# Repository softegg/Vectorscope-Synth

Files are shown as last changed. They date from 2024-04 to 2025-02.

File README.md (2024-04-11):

# Music Synthesizer for the Hackaday Supercon 2024/ Europe 2024 Vectorscope Badge

This is an add on for the Hackaday Superconference 2023 / Hackaday Europe(Berlin) 2024 Vectorscope badge that adds a small virtual analog synthesizer based on the [Stylish Trucker Belt Synthesizer](https://github.com/softegg/Stylish-Trucker-Belt-Synthesizer).

It should work with all of the source code from that, so for now get it there.
This has not yet been tested, so if you want to build one, be aware that it might be broken. In particular, I'm worried that the two batteries in the badge might not have the oomph to drive the vectorscope with the RPI 2040 and screen as well as the synth's Bluepill STM32, LED ring, and amplifier.

This might need additional battery or USB power support.

The design is very much in flux as we have very limited time before the show, and the modules used in the end product are going to be limited by what we can get delivered quickly in Berlin, as two week+ lead times for AliExpress parts are just not doable!
This is intended for a workshop, but we've been reluctant to commit before we are sure that it will work and that we can get the parts.

So, you might be able to do a $20 workshop and get one, or you might have to go find parts and build your own. It might work, or it might be crap.

There is so much we don't know.

I hope you can enjoy it, at least!!

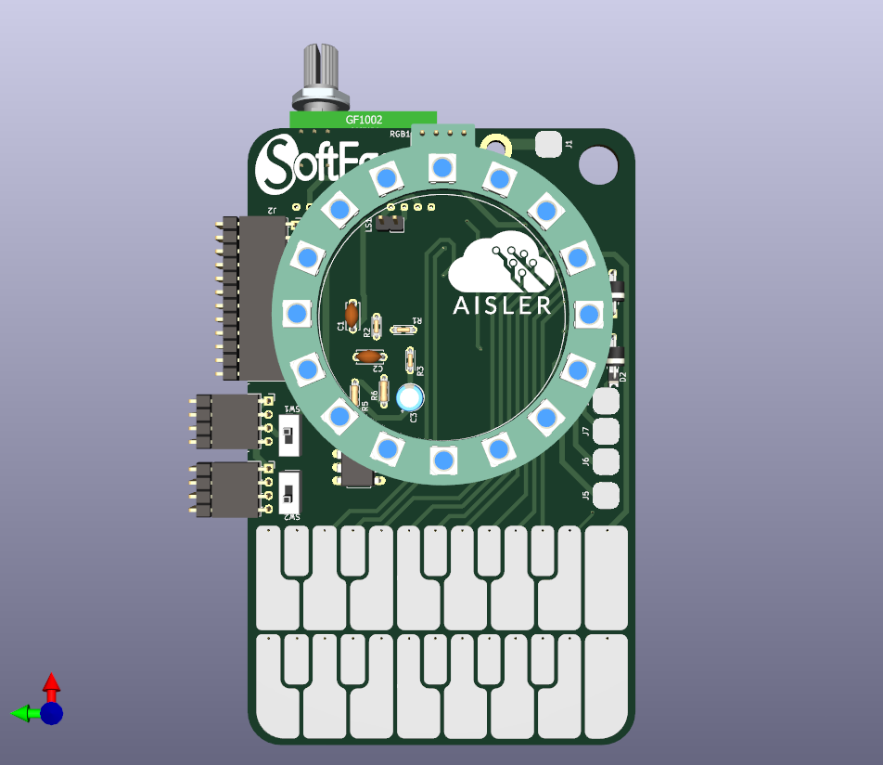
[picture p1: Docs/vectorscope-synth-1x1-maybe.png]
Vectorscope Synth Front


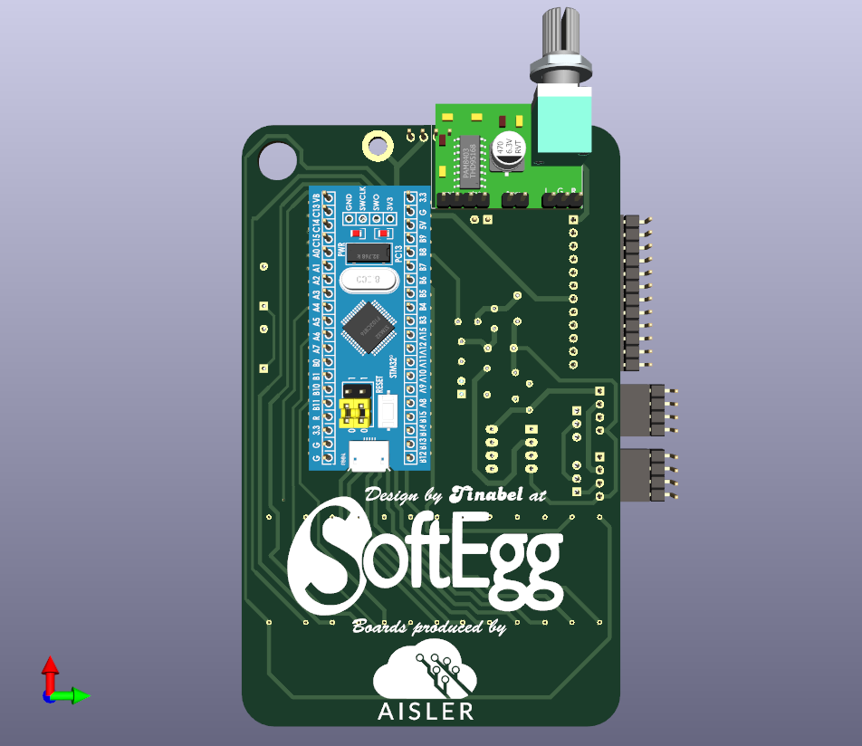
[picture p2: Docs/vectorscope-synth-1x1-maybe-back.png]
Vectorscope Synth Back


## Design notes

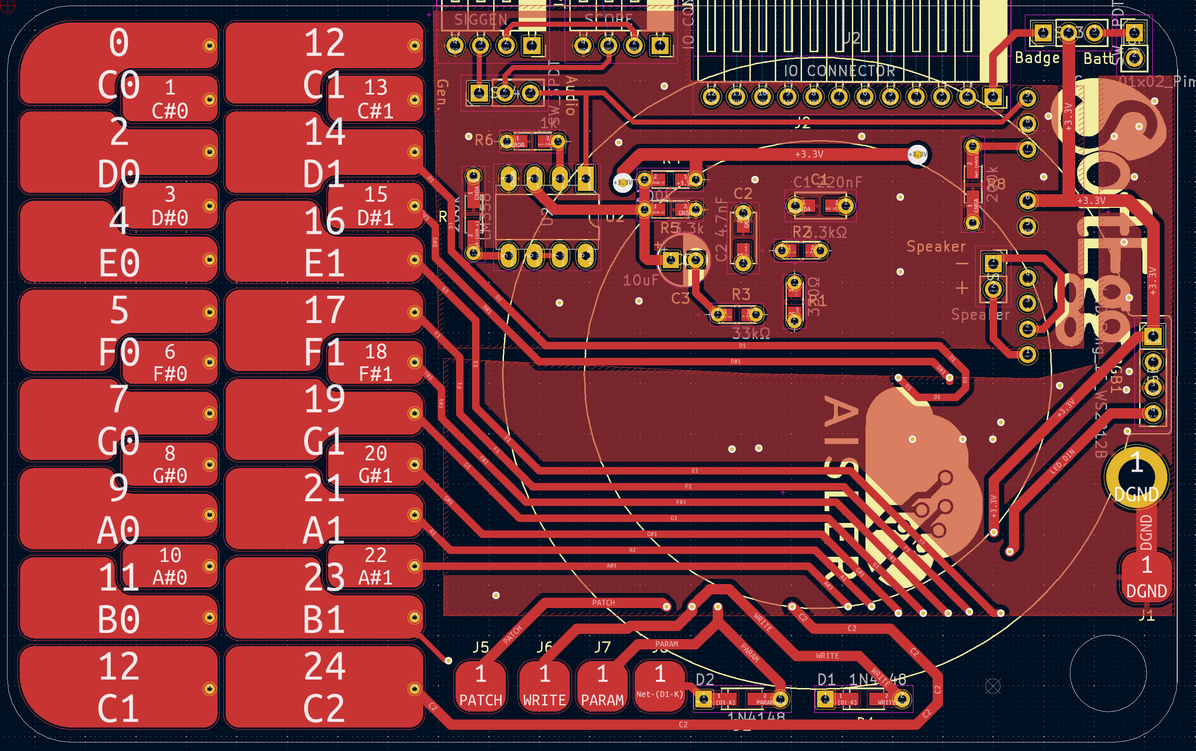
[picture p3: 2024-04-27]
Docs/Vectorscope Synth PCB front CAD.PNG

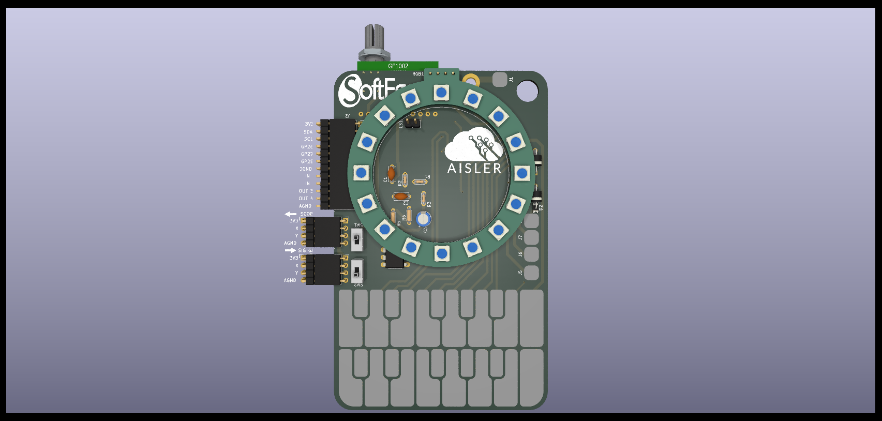
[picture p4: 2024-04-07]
Docs/vectorscope-synth-16x9-maybe-ray.png

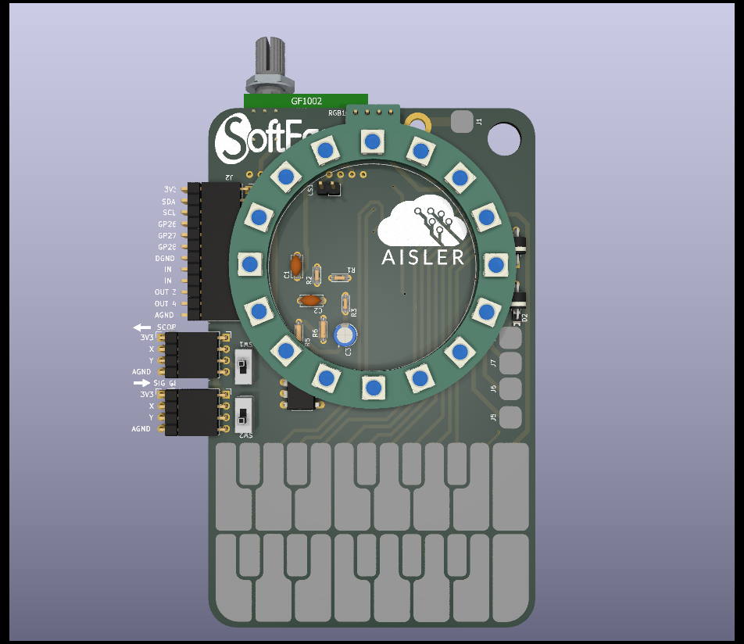
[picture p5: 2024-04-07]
Docs/vectorscope-synth-1x1-maybe-ray.png

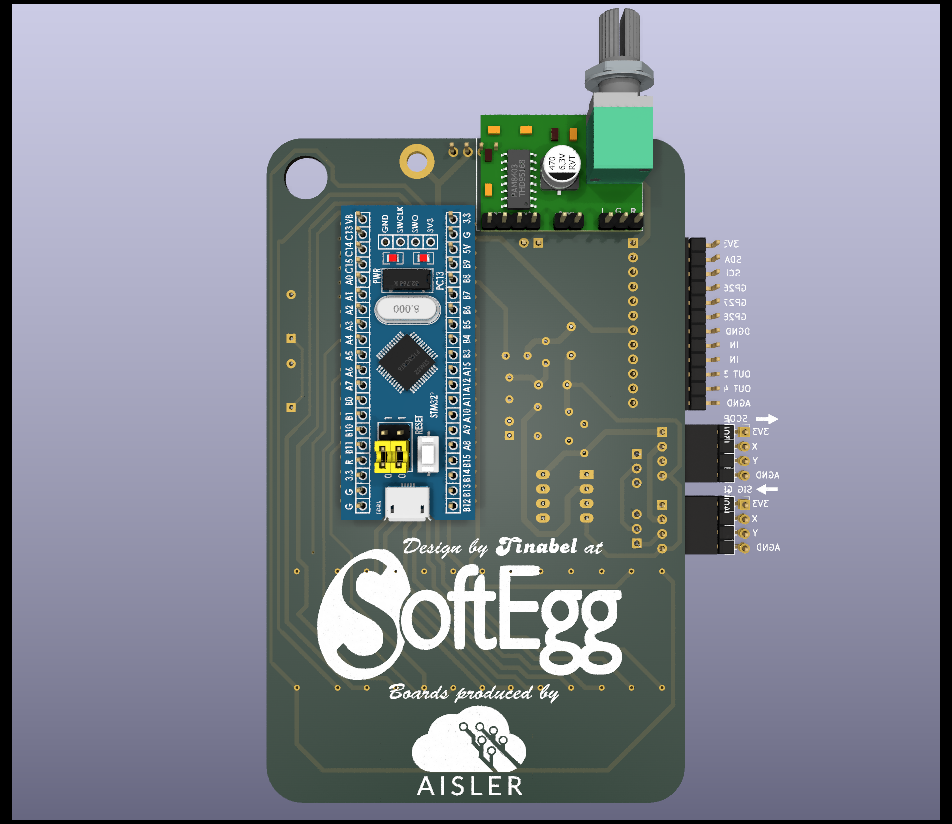
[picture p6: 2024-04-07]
Docs/vectorscope-synth-1x1-maybe-back-ray.png

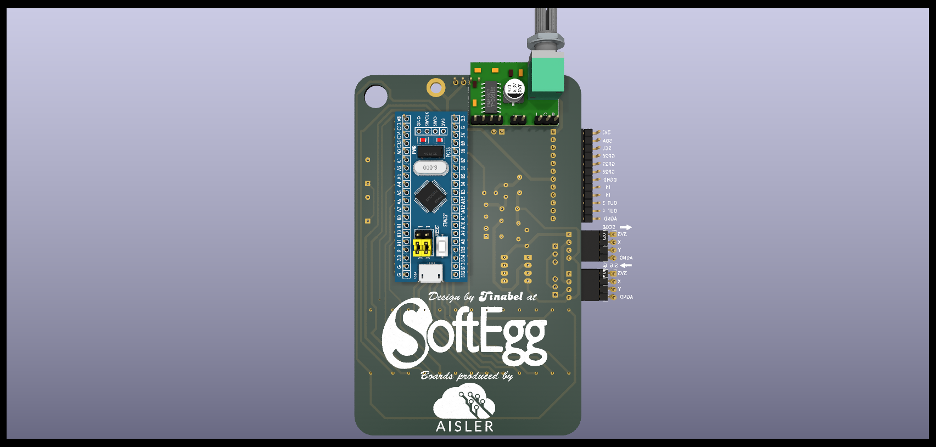
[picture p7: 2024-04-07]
Docs/vectorscope-synth-16x9-maybe-back-ray.png

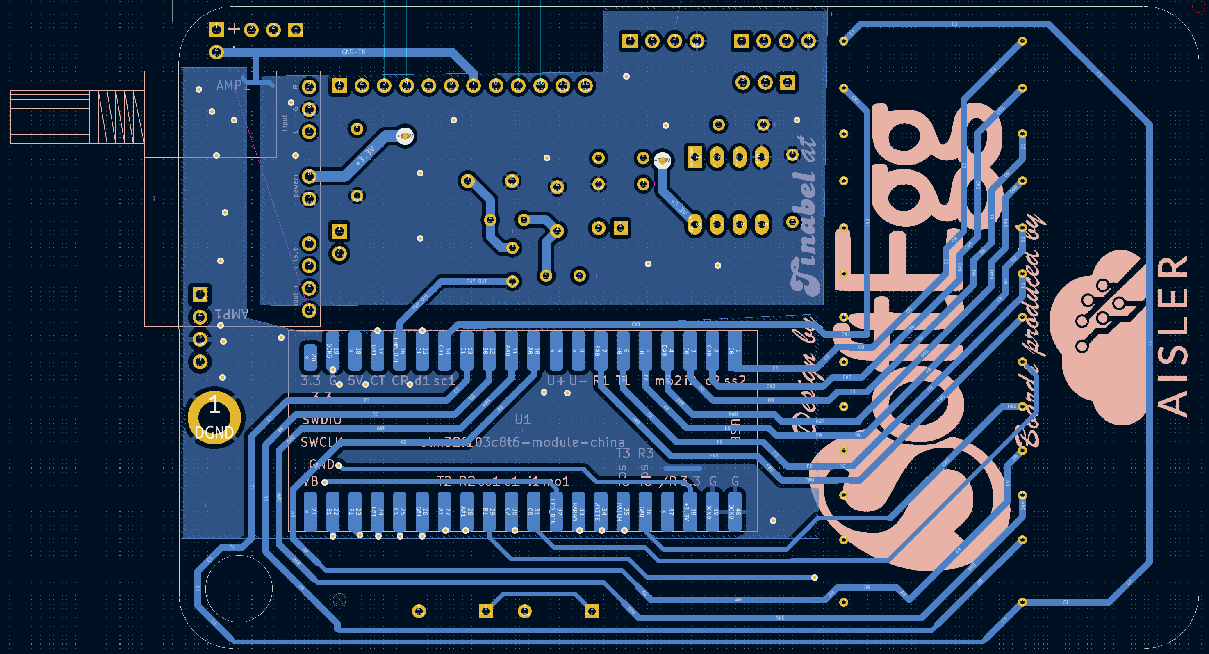
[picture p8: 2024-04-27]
Docs/Vectorscope Synth PCB back CAD.PNG

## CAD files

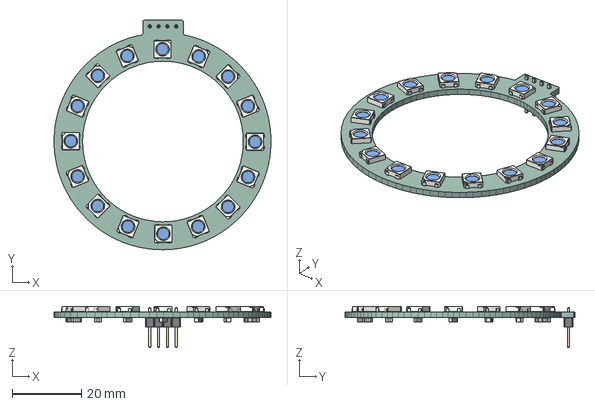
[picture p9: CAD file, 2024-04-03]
WS2812B-16-LED-RING.step
62.6 x 66.2 x 11.9 mm
WS2812B-16-LED-RING PCB

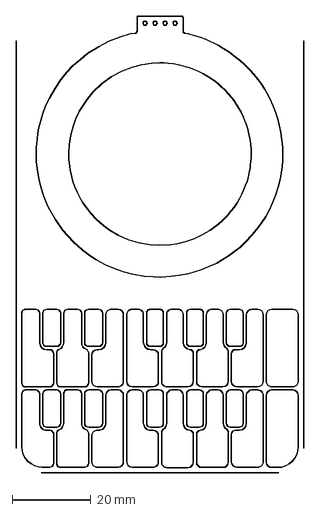
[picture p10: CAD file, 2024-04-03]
StylusKeyboardLayout.dxf
73.0 x 116.0 mm

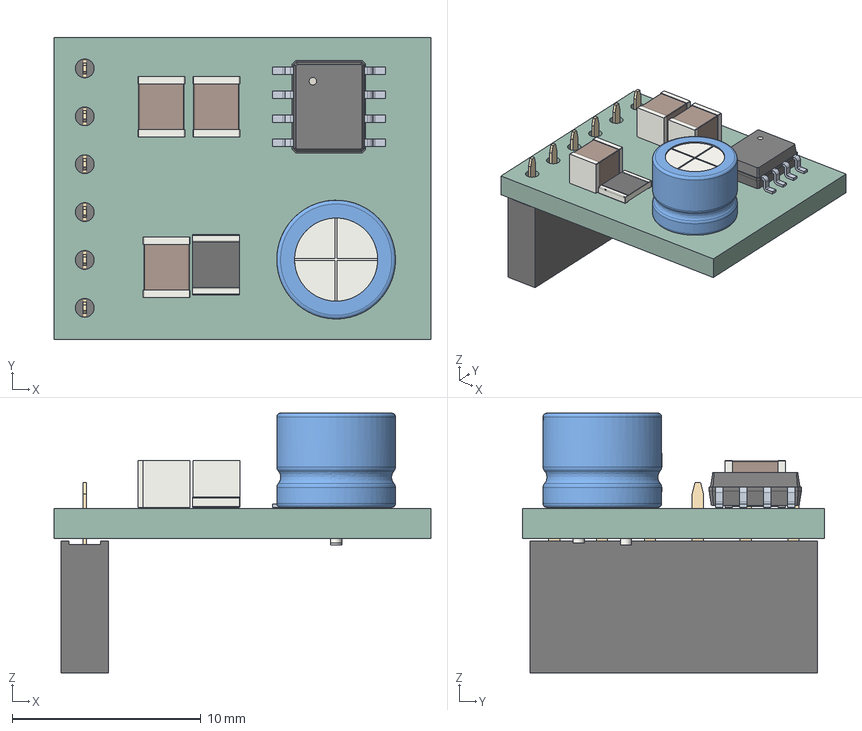
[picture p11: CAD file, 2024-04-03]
XH-M125-amp-board.step
20.0 x 16.0 x 13.8 mm
XH-M125-amp-board PCB

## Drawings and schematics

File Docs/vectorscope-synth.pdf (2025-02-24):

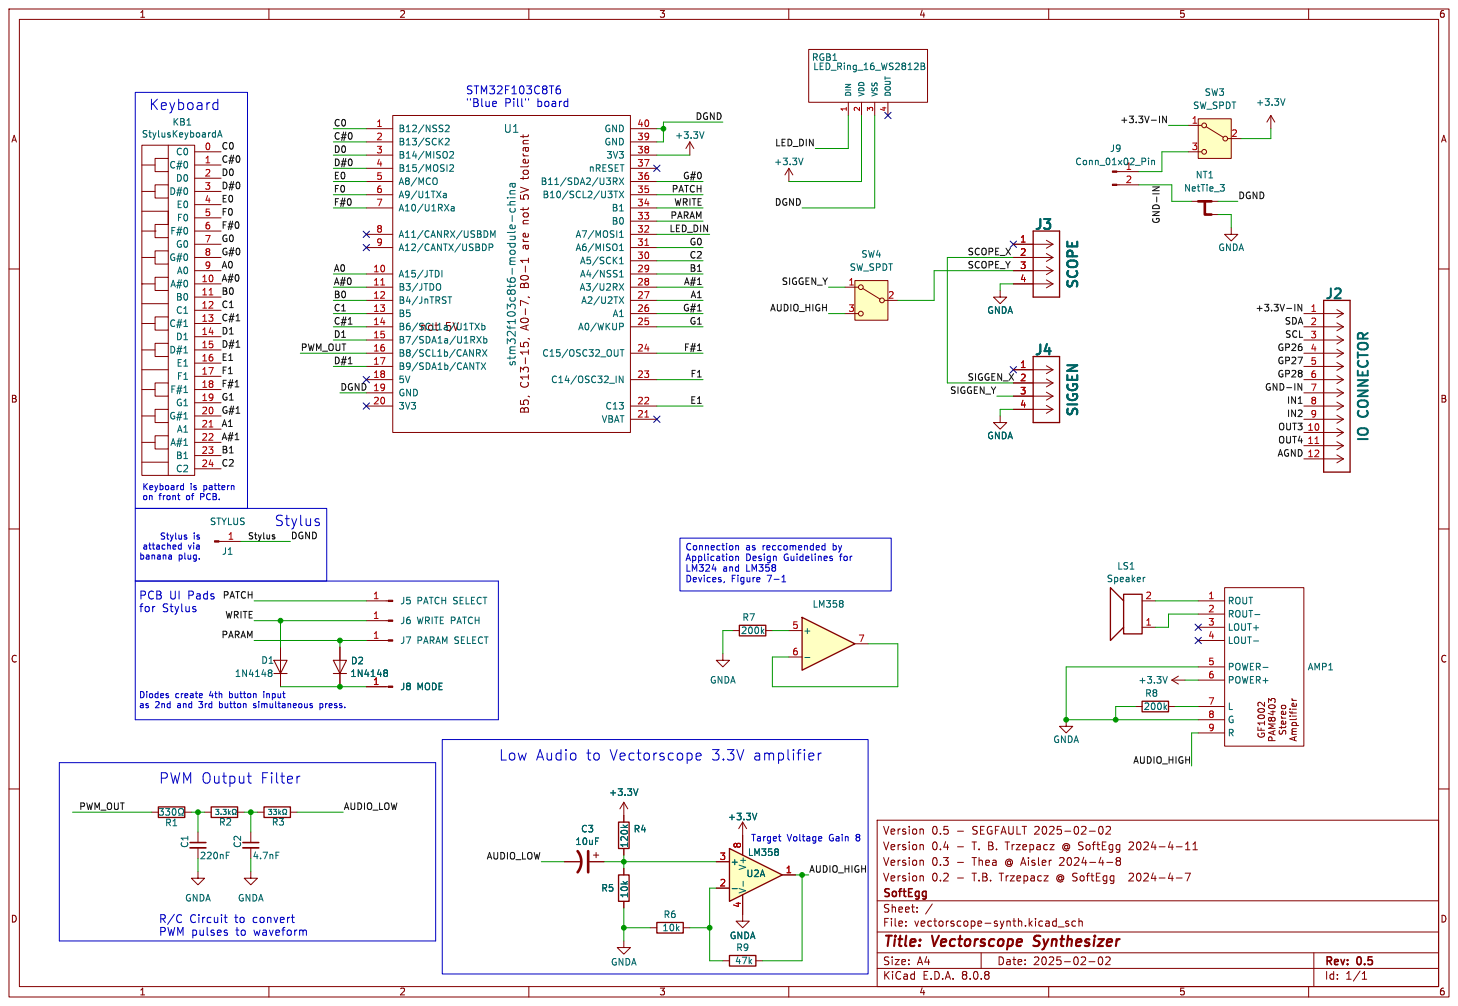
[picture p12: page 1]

"Blue Pill" board PWM Output Filter

4.7nF GNDA R1
Target Voltage Gain 8 R/C Circuit to convert PWM pulses to waveform

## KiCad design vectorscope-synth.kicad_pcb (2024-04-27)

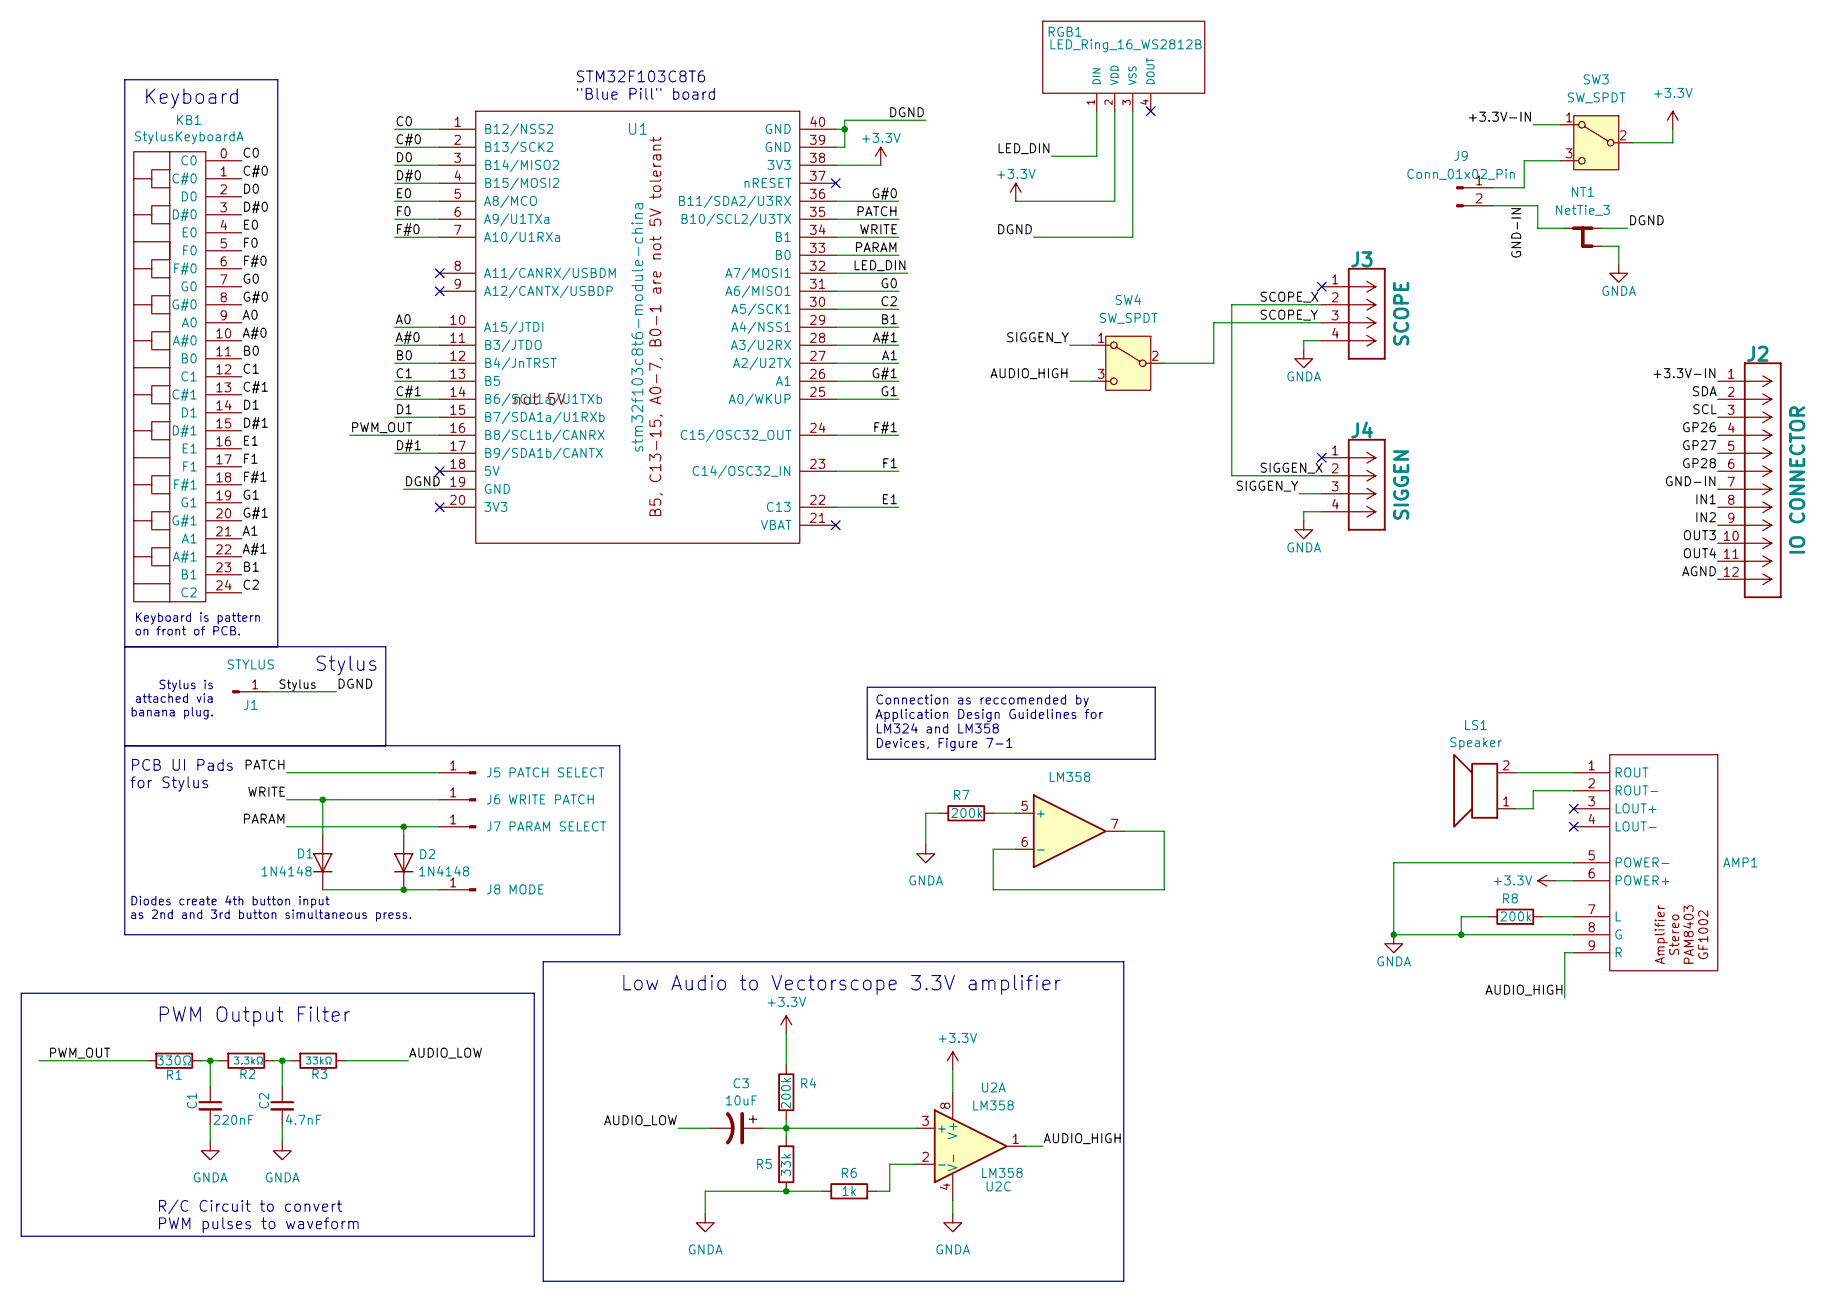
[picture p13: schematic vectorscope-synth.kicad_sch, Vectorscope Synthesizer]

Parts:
AMP1: GF1002-PAM8403_Amplifier_Module
C1: 220nF; C_Disc_D5.0mm_W2.5mm_P5.00mm+SMD
C2: 4.7nF; C_Disc_D5.0mm_W2.5mm_P5.00mm+SMD
C3: 10uF; CP_Radial_D5.0mm_P2.50mm
D1, D2: 1N4148; D_DO-35_SOD27_P7.62mm_Horizontal+SMD
J1: STYLUS; SmallRoundTouchPad
J2: IO CONNECTOR; PinSocket_1x12_P2.54mm_Horizontal
J3: SCOPE; PinSocket_1x04_P2.54mm_Horizontal
J4: SIGGEN; PinSocket_1x04_P2.54mm_Horizontal
J5: PATCH SELECT; SmallRoundTouchPad
J6: WRITE PATCH; SmallRoundTouchPad
J7: PARAM SELECT; SmallRoundTouchPad
J8: MODE; SmallRoundTouchPad
J9: Conn_01x02_Pin; PinHeader_1x02_P2.54mm_Vertical
KB1: StylusKeyboardA; StylusKeyboard
LS1: Speaker; PinSocket_1x02_P2.54mm_Vertical
NT1: NetTie_3; NetTie-3_SMD_Pad0.5mm
R1: 330Ω; R_Axial_DIN0204_L3.6mm_D1.6mm_P3.81mm_Horizontal+SMD804
R2: 3.3kΩ; R_Axial_DIN0204_L3.6mm_D1.6mm_P3.81mm_Horizontal+SMD804
R3: 33kΩ; R_Axial_DIN0204_L3.6mm_D1.6mm_P3.81mm_Horizontal+SMD804
R4: 200k; R_Axial_DIN0204_L3.6mm_D1.6mm_P5mm_Horizontal+SMD804
R5: 33k; R_Axial_DIN0204_L3.6mm_D1.6mm_P5mm_Horizontal+SMD804
R6: 1k; R_Axial_DIN0204_L3.6mm_D1.6mm_P5mm_Horizontal+SMD804
R7, R8: 200k; R_Axial_DIN0204_L3.6mm_D1.6mm_P7.62mm_Horizontal+SMD804
RGB1: LED_Ring_16_WS2812B; LED RING 16 WS2812B
SW3, SW4: SW_SPDT; PinHeader_1x03_P2.54mm_Vertical
U1: stm32f103c8t6-module-china; stm32f103c8t6-module-china-smd
U2: LM358; DIP-8_W7.62mm_LongPads

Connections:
+3.3V: AMP1.6 (POWER+), R4.1, RGB1.2 (VDD), SW3.2 (B), U1.38 (3V3), U2.8 (V+)
/+3.3V-IN: J2.1, SW3.1 (A)
/A0: KB1.9 (A0), U1.10 (A15/JTDI)
/A1: KB1.21 (A1), U1.27 (A2/U2TX)
/A#0: KB1.10 (A#0), U1.11 (B3/JTDO)
/A#1: KB1.22 (A#1), U1.28 (A3/U2RX)
/AGND: J2.12
/AUDIO_HIGH: AMP1.9 (R), SW4.3 (C), U2.1
/AUDIO_LOW: C3.2, R3.1
/B0: KB1.11 (B0), U1.12 (B4/JnTRST)
/B1: KB1.23 (B1), U1.29 (A4/NSS1)
/C0: KB1.0 (C0), U1.1 (B12/NSS2)
/C1: KB1.12 (C1), U1.13 (B5)
/C2: KB1.24 (C2), U1.30 (A5/SCK1)
/C#0: KB1.1 (C#0), U1.2 (B13/SCK2)
/C#1: KB1.13 (C#1), U1.14 (B6/SCL1a/U1TXb)
/D0: KB1.2 (D0), U1.3 (B14/MISO2)
/D1: KB1.14 (D1), U1.15 (B7/SDA1a/U1RXb)
/D#0: KB1.3 (D#0), U1.4 (B15/MOSI2)
/D#1: KB1.15 (D#1), U1.17 (B9/SDA1b/CANTX)
/DGND: J1.1, NT1.1, RGB1.3 (VSS), U1.19 (GND), U1.39 (GND), U1.40 (GND)
/E0: KB1.4 (E0), U1.5 (A8/MCO)
/E1: KB1.16 (E1), U1.22 (C13)
/F0: KB1.5 (F0), U1.6 (A9/U1TXa)
/F1: KB1.17 (F1), U1.23 (C14/OSC32_IN)
/F#0: KB1.6 (F#0), U1.7 (A10/U1RXa)
/F#1: KB1.18 (F#1), U1.24 (C15/OSC32_OUT)
/G0: KB1.7 (G0), U1.31 (A6/MISO1)
/G1: KB1.19 (G1), U1.25 (A0/WKUP)
/G#0: KB1.8 (G#0), U1.36 (B11/SDA2/U3RX)
/G#1: KB1.20 (G#1), U1.26 (A1)
/GND-IN: J2.7, J9.2, NT1.2
/GP26: J2.4; also elsewhere on the board
/GP27: J2.5; also elsewhere on the board
/GP28: J2.6; also elsewhere on the board
/IN1: J2.8; also elsewhere on the board
/IN2: J2.9; also elsewhere on the board
/LED_DIN: RGB1.1 (DIN), U1.32 (A7/MOSI1)
/OUT3: J2.10; also elsewhere on the board
/OUT4: J2.11; also elsewhere on the board
/PARAM: D2.2 (A), J7.1, U1.33 (B0)
/PATCH: J5.1, U1.35 (B10/SCL2/U3TX)
/PWM_OUT: R1.2, U1.16 (B8/SCL1b/CANRX)
/SCL: J2.3; also elsewhere on the board
/SCOPE_X: J3.2, J4.2
/SCOPE_Y: J3.3, SW4.2 (B)
/SDA: J2.2; also elsewhere on the board
/SIGGEN_Y: J4.3, SW4.1 (A)
/WRITE: D1.2 (A), J6.1, U1.34 (B1)
GNDA: AMP1.5 (POWER-), AMP1.8 (G), C1.2, C2.2, J3.4, J4.4, NT1.3, R5.2, R6.1, R7.1, R8.1, U2.4 (V-); also elsewhere on the board
unnamed: AMP1.7 (L), R8.2
unnamed: AMP1.1 (ROUT), LS1.2
unnamed: AMP1.2 (ROUT-), LS1.1
unnamed: C1.1, R1.1, R2.2
unnamed: C2.1, R2.1, R3.2
unnamed: D1.1 (K), D2.1 (K), J8.1
unnamed: J9.1, SW3.3 (C)
unnamed: C3.1, R4.2, R5.1, U2.3 (+)
unnamed: R6.2, U2.2 (-)
unnamed: R7.2, U2.5 (+)
unnamed: U2.6 (-), U2.7

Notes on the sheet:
Connection as reccomended by Application Design Guidelines for LM324 and LM358 Devices, Figure 7-1
Stylus
PWM Output Filter
STM32F103C8T6 "Blue Pill" board
R/C Circuit to convert PWM pulses to waveform
Keyboard is pattern on front of PCB.
PCB UI Pads for Stylus
Keyboard
Low Audio to Vectorscope 3.3V amplifier
Stylus is attached via banana plug.
Diodes create 4th button input as 2nd and 3rd button simultaneous press.

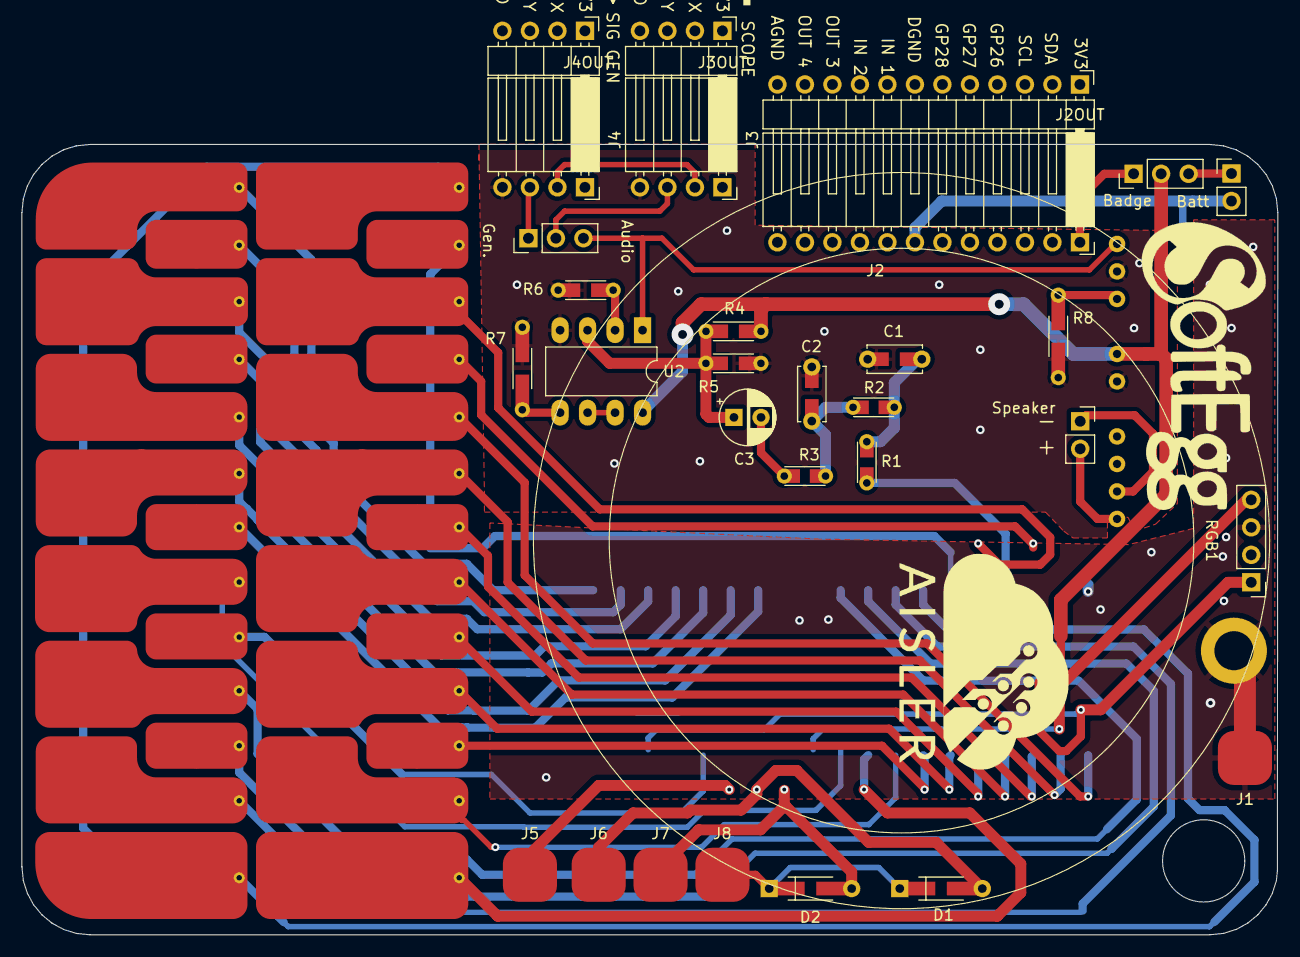
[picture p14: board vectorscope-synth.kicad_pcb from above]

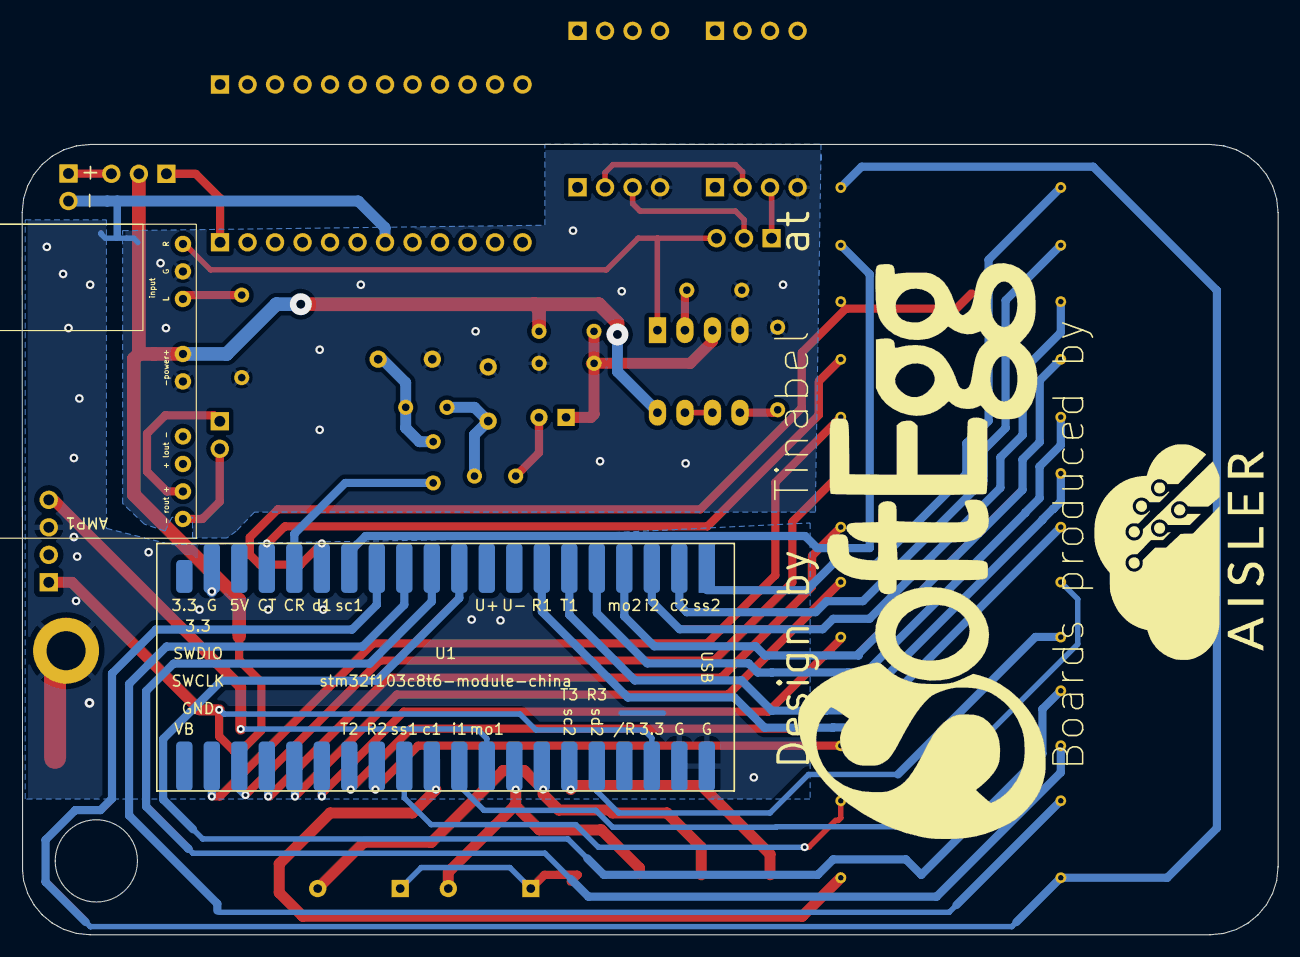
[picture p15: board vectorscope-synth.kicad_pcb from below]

Board: 2 copper layers, 116.0 x 73.0 mm, 34 parts (3 on the bottom side), 60 nets.

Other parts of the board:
J2OUT: IO CONNECTOR; PinHeader_1x12_P2.54mm_Horizontal
J3OUT: SCOPE; PinHeader_1x04_P2.54mm_Horizontal
J4OUT: SIGGEN; PinHeader_1x04_P2.54mm_Horizontal

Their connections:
/GP26: J2OUT.4; also elsewhere on the board
/GP27: J2OUT.5; also elsewhere on the board
/GP28: J2OUT.6; also elsewhere on the board
/IN1: J2OUT.8; also elsewhere on the board
/IN2: J2OUT.9; also elsewhere on the board
/OUT3: J2OUT.10; also elsewhere on the board
/OUT4: J2OUT.11; also elsewhere on the board
/SCL: J2OUT.3; also elsewhere on the board
/SDA: J2OUT.2; also elsewhere on the board
GNDA: J3OUT.4, J4OUT.4; also elsewhere on the board

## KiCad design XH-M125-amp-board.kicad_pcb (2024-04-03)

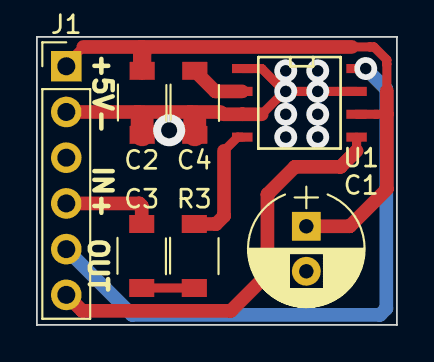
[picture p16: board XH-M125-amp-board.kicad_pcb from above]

Board: 2 copper layers, 20.0 x 16.0 mm, 7 parts (0 on the bottom side), 8 nets.

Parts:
C1: 470uF; CP_Radial_D6.3mm_P2.50mm
C2, C4: 1uF; C_1509
C3: 0.39uF; C_1509
J1: Conn_01x06; Pin_Header_Straight_1x06_Pitch2.54mm
R3: R; C_1509
U1: XPT8871; SOIC-8-N

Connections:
/GND: C1.2, C2.2, C4.2, J1.2, J1.3, U1.1, U1.3, U1.7
/VCC: C1.1, C2.1, J1.1, U1.6
/VIN: C3.2, J1.4
/VO1: J1.6, U1.5
/VO2: J1.5, U1.8
unnamed: C3.1, R3.2
unnamed: C4.1, U1.2
unnamed: R3.1, U1.4

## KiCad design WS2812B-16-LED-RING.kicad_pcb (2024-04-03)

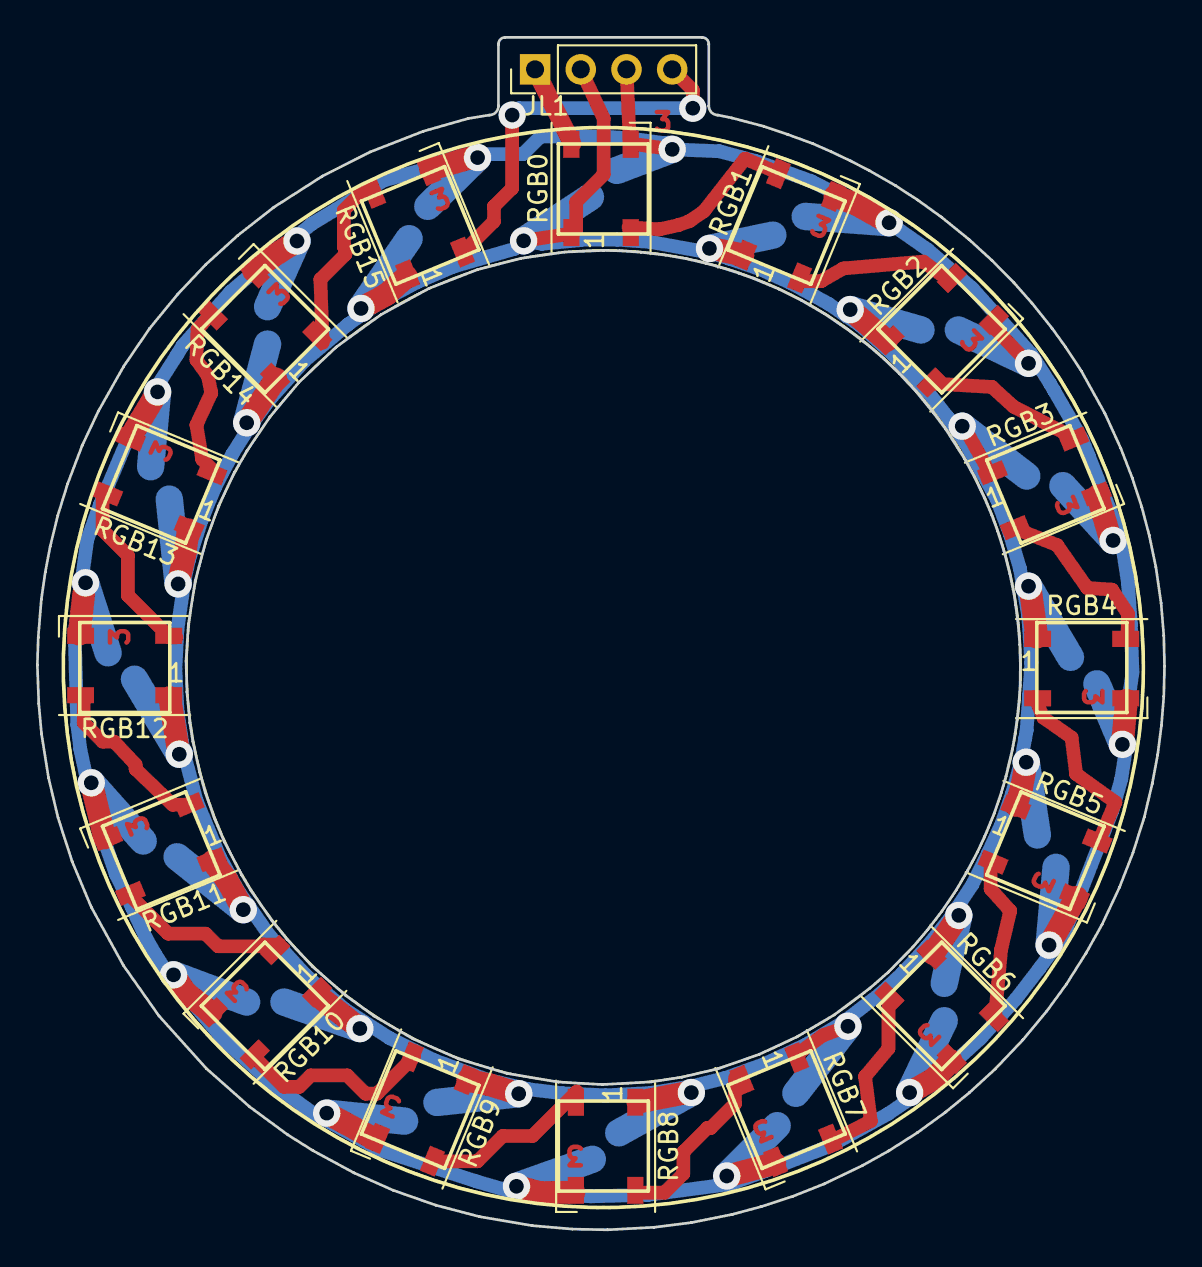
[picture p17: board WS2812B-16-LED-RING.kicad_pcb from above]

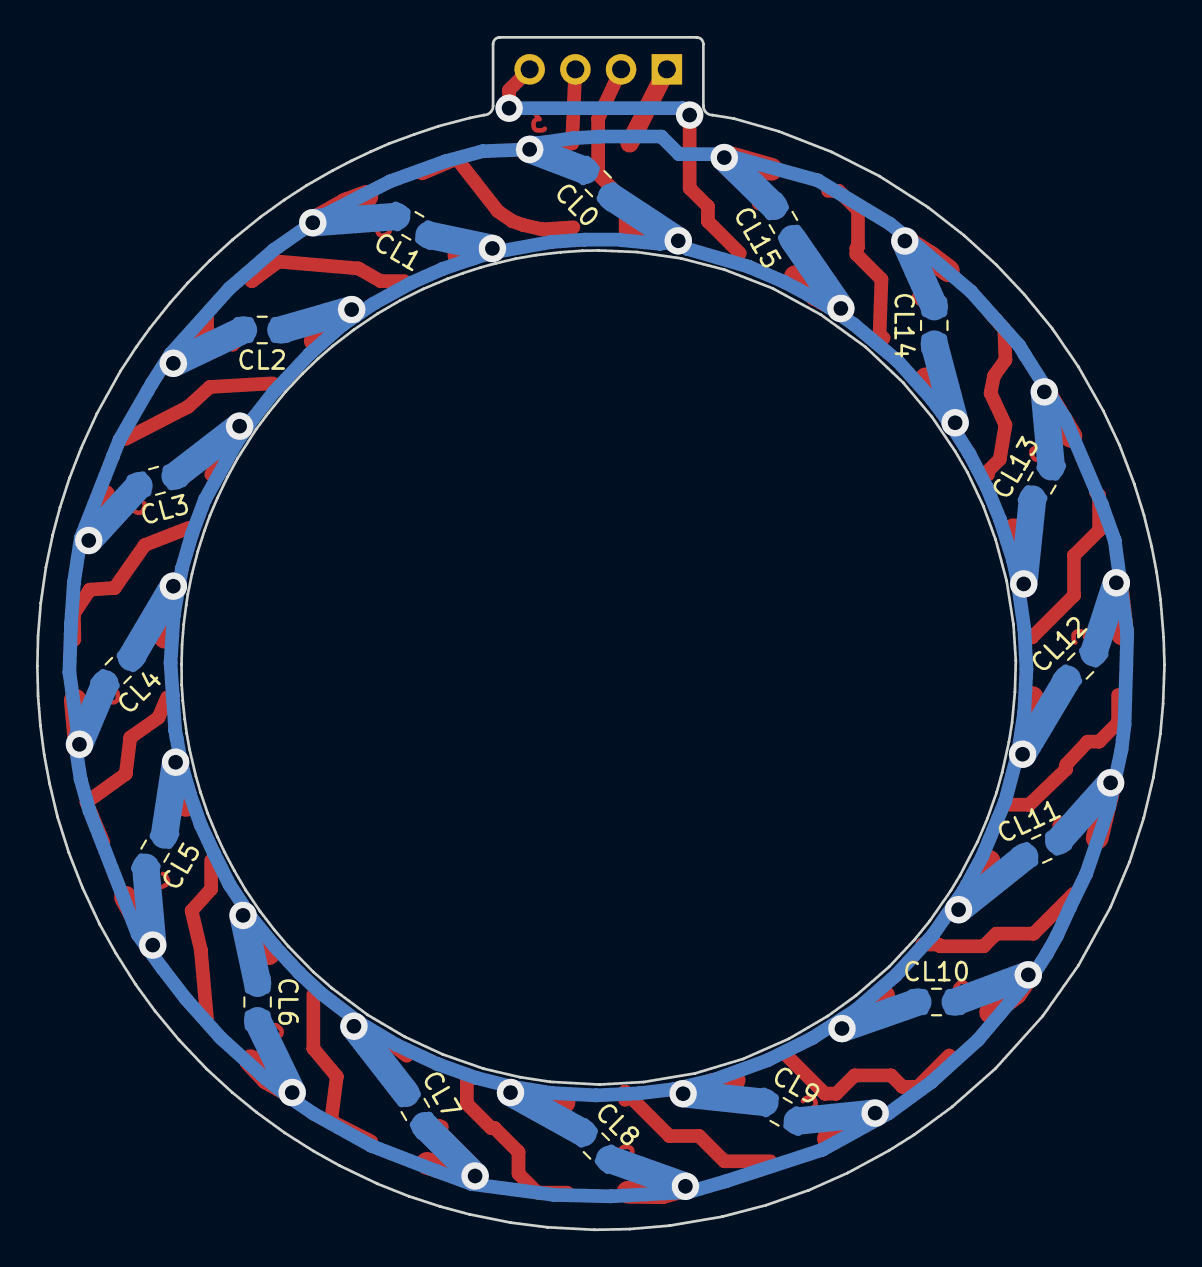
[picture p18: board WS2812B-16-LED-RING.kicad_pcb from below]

Board: 2 copper layers, 62.6 x 66.2 mm, 33 parts (16 on the bottom side), 19 nets.

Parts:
CL0, CL1, CL2, CL3, CL4, CL5, CL6, CL7, CL8, CL9, CL10, CL11, CL12, CL13, CL14, CL15: 104; C_0805_2012Metric_Pad1.18x1.45mm_HandSolder
JL1: Pin_Header_Straight_1x04_Pitch2.54mm
RGB0, RGB1, RGB2, RGB3, RGB4, RGB5, RGB6, RGB7, RGB8, RGB9, RGB10, RGB11, RGB12, RGB13, RGB14, RGB15: WS2812B; LED_WS2812B_PLCC4_5.0x5.0mm_P3.2mm

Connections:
/DIN: JL1.1, RGB0.4 (DIN)
/DOUT: JL1.4, RGB15.2 (DOUT)
/VIN: CL0.1, CL1.1, CL2.1, CL3.1, CL4.1, CL5.1, CL6.1, CL7.1, CL8.1, CL9.1, CL10.1, CL11.1, CL12.1, CL13.1, CL14.1, CL15.1, JL1.2, RGB0.1 (VDD), RGB1.1 (VDD), RGB2.1 (VDD), RGB3.1 (VDD), RGB4.1 (VDD), RGB5.1 (VDD), RGB6.1 (VDD), RGB7.1 (VDD), RGB8.1 (VDD), RGB9.1 (VDD), RGB10.1 (VDD), RGB11.1 (VDD), RGB12.1 (VDD), RGB13.1 (VDD), RGB14.1 (VDD), RGB15.1 (VDD)
GND: CL0.2, CL1.2, CL2.2, CL3.2, CL4.2, CL5.2, CL6.2, CL7.2, CL8.2, CL9.2, CL10.2, CL11.2, CL12.2, CL13.2, CL14.2, CL15.2, JL1.3, RGB0.3 (VSS), RGB1.3 (VSS), RGB2.3 (VSS), RGB3.3 (VSS), RGB4.3 (VSS), RGB5.3 (VSS), RGB6.3 (VSS), RGB7.3 (VSS), RGB8.3 (VSS), RGB9.3 (VSS), RGB10.3 (VSS), RGB11.3 (VSS), RGB12.3 (VSS), RGB13.3 (VSS), RGB14.3 (VSS), RGB15.3 (VSS)
unnamed: RGB0.2 (DOUT), RGB1.4 (DIN)
unnamed: RGB1.2 (DOUT), RGB2.4 (DIN)
unnamed: RGB2.2 (DOUT), RGB3.4 (DIN)
unnamed: RGB3.2 (DOUT), RGB4.4 (DIN)
unnamed: RGB4.2 (DOUT), RGB5.4 (DIN)
unnamed: RGB5.2 (DOUT), RGB6.4 (DIN)
unnamed: RGB6.2 (DOUT), RGB7.4 (DIN)
unnamed: RGB7.2 (DOUT), RGB8.4 (DIN)
unnamed: RGB8.2 (DOUT), RGB9.4 (DIN)
unnamed: RGB9.2 (DOUT), RGB10.4 (DIN)
unnamed: RGB10.2 (DOUT), RGB11.4 (DIN)
unnamed: RGB11.2 (DOUT), RGB12.4 (DIN)
unnamed: RGB12.2 (DOUT), RGB13.4 (DIN)
unnamed: RGB13.2 (DOUT), RGB14.4 (DIN)
unnamed: RGB14.2 (DOUT), RGB15.4 (DIN)

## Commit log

2024-04-03 Vectorscope Synth KiCAD version 0.1 complete Uses Bluepill STM32F103C8T6 microcontroller A generic WS2812B 16 LED Ring An XH-M125 XPT8871 Amplifier Board and a handful of passives for a low pass filt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
    [StylusKeyboardLayout.dxf, WS2812B-16-LED-RING.kicad_pcb, WS2812B-16-LED-RING.kicad_sch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]
2024-04-03 Credits, and schematic PDF
    [vectorscope-synth.kicad_sch]
2024-04-07 Added op amp LM358 circuit to move PWM levels to vectorscope 0-3.3v. Replaced XH-M125/XPT8871 amp with GF1002/PAM8403 stereo amp with volume control. Enlarged many traces. Added logos for SoftEgg and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
    [vectorscope-synth.kicad_pcb, vectorscope-synth.kicad_sch]
2024-04-11 PCB and Schematic updates by Thea @ Aisler
    [vectorscope-synth.kicad_pcb, vectorscope-synth.kicad_sch]
2024-04-11 Note: This is NOT the version used in the Hackaday Europe 2024 Workshop, that is the previous version. This is a version that fixes the LED ring wiring problem with that one, and has a footprint that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
    [WS2812B-16-LED-RING.kicad_sch, vectorscope-synth.kicad_pcb, vectorscope-synth.kicad_sch]
2024-04-11 Changed Resstor to give good values for the vector scope. Updated headers to give proper credits.
    [vectorscope-synth.kicad_pcb, vectorscope-synth.kicad_sch]
2024-04-27 Enlarged holes for amplifier PCB mounting. Updated PCB pics and Schematic PDF to match revisions.
    [vectorscope-synth.kicad_pcb]
2024-04-27 Was there a change that was not checked in?
    [vectorscope-synth.kicad_pcb]
2025-02-02 propsed solution to amp problem
    [vectorscope-synth.kicad_sch]
2025-02-24 correct patch resistor values for updated measurements
    [vectorscope-synth.kicad_sch]
